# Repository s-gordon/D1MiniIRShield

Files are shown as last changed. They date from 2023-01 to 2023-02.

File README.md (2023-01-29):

# D1 Mini IR Shield

## Description

TODO

## Preview

| 3D | 2D |
| -- | -- |
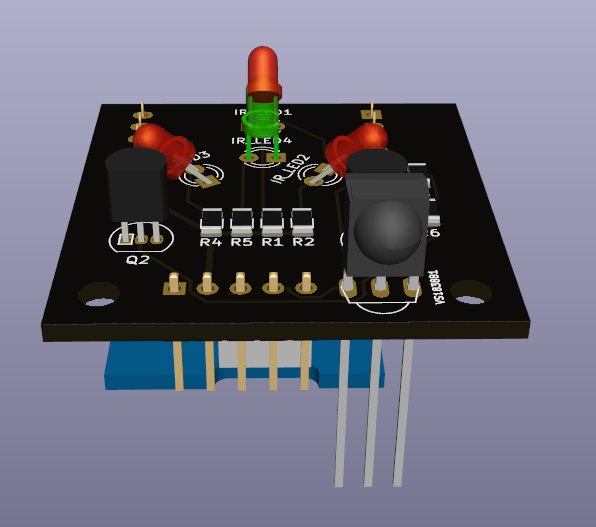
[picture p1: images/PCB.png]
3-dimensional view
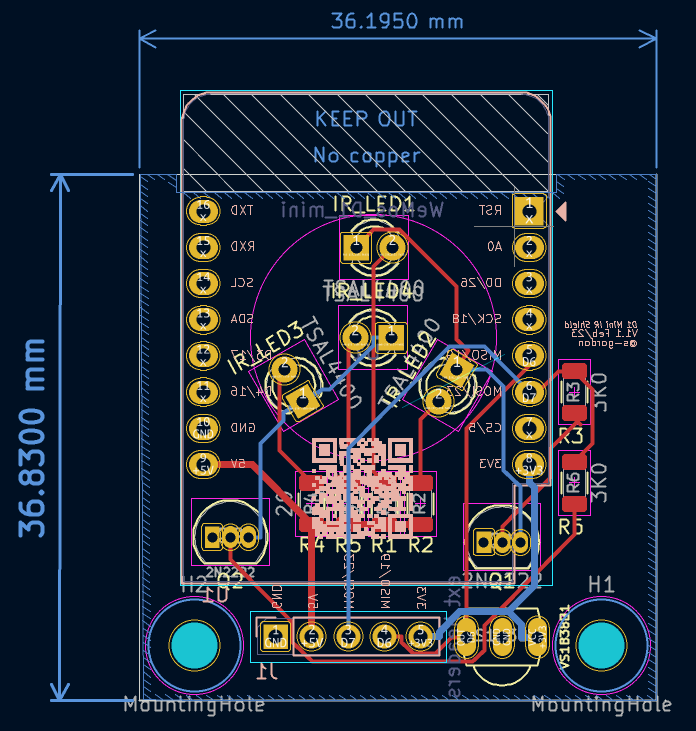
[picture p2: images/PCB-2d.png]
2-dimensional view
|  |  |

## Credit

TODO

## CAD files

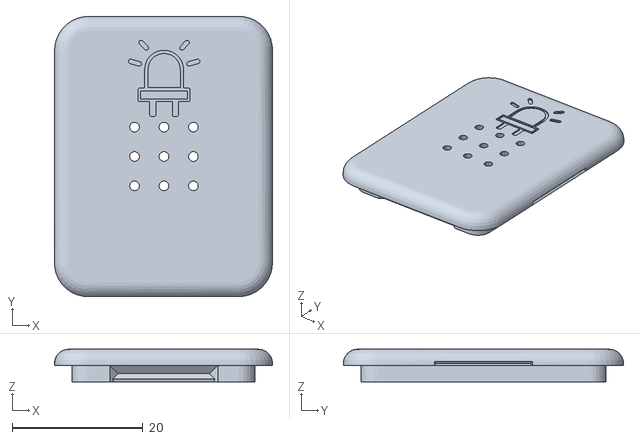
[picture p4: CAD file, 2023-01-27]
stl/case/lid.stl
33.3 x 42.9 x 5.00

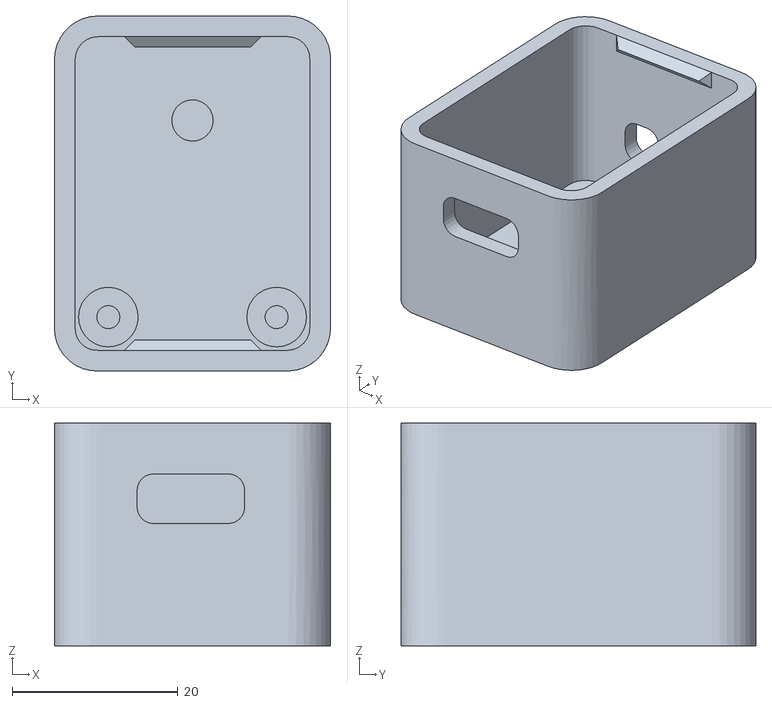
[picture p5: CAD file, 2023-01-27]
stl/case/base.stl
33.3 x 42.9 x 26.9

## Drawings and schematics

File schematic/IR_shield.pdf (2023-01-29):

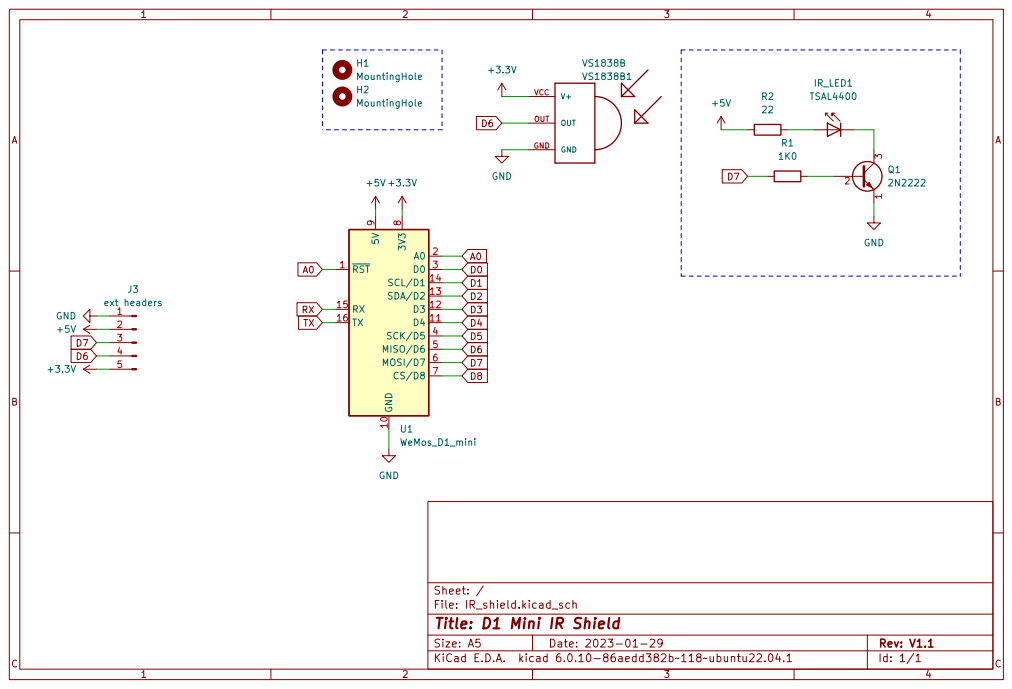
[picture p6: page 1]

Id: 1/1 Title: D1 Mini IR Shield

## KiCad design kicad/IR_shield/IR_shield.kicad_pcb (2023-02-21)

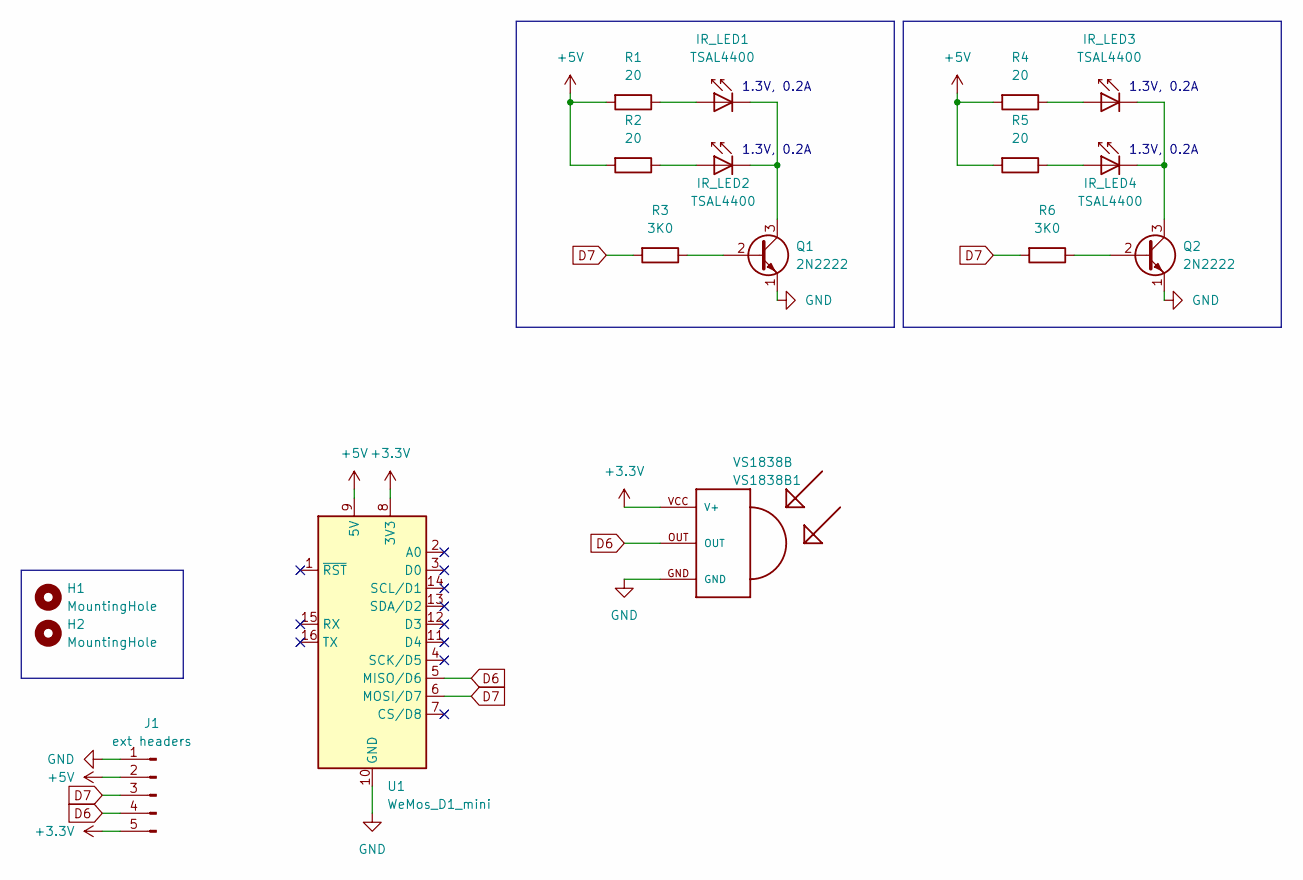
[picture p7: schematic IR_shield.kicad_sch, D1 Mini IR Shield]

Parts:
H1, H2: MountingHole; MountingHole_3.2mm_M3
IR_LED1, IR_LED2, IR_LED3, IR_LED4: TSAL4400; LED_D3.0mm
J1: ext headers; PinHeader_1x05_P2.54mm_Vertical
Q1, Q2: 2N2222; TO-92_Inline
R1, R2, R4, R5: 20; R_1206_3216Metric
R3, R6: 3K0; R_1206_3216Metric
U1: WeMos_D1_mini; WEMOS_D1_mini_light
VS1838B1: VS1838B; TSOP18XX

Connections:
+3V3: J1.5, U1.8 (3V3), VS1838B1.VCC (V+)
+5V: J1.2, R1.2, R2.2, R4.2, R5.2, U1.9 (5V)
D6: J1.4, U1.5 (MISO/D6), VS1838B1.OUT
D7: J1.3, R3.2, R6.2, U1.6 (MOSI/D7)
GND: J1.1, Q1.1 (E), Q2.1 (E), U1.10 (GND), VS1838B1.GND
unnamed: IR_LED1.1 (K), IR_LED2.1 (K), Q1.3 (C)
unnamed: IR_LED1.2 (A), R1.1
unnamed: IR_LED2.2 (A), R2.1
unnamed: IR_LED3.1 (K), IR_LED4.1 (K), Q2.3 (C)
unnamed: IR_LED3.2 (A), R4.1
unnamed: IR_LED4.2 (A), R5.1
unnamed: Q1.2 (B), R3.1
unnamed: Q2.2 (B), R6.1

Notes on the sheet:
1.3V, 0.2A

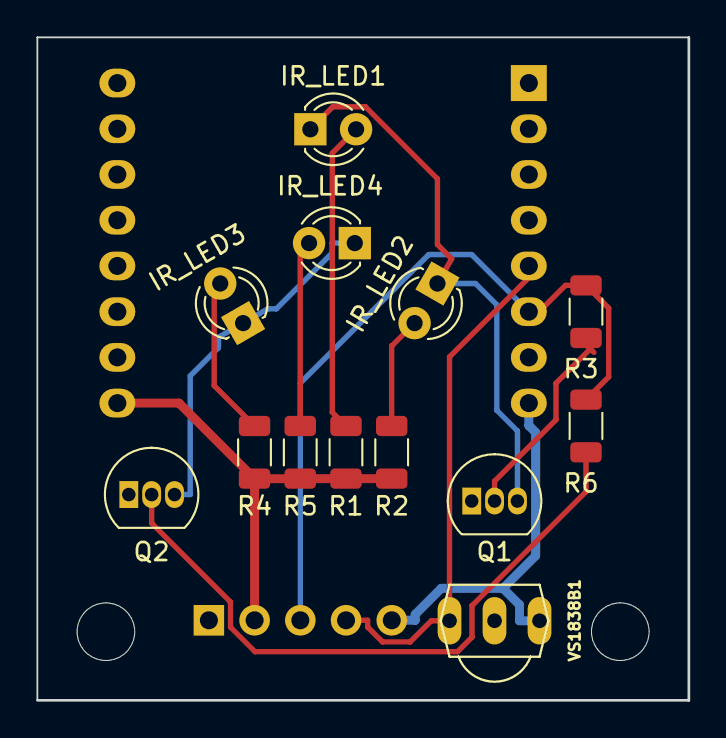
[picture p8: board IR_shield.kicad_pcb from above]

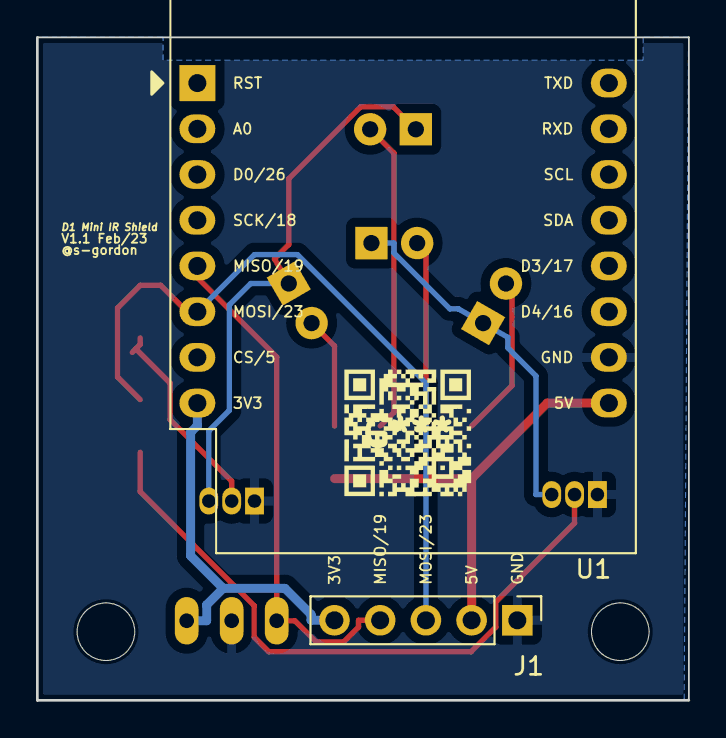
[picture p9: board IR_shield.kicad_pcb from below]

Board: 2 copper layers, 36.2 x 36.8 mm, 17 parts (2 on the bottom side), 13 nets.

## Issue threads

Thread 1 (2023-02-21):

v1.0 RC1

s-gordon, 2023-02-21:
I've ordered a set of the v1.0-RC1 board to be fabricated. These will need to be tested to make sure that everything works as expected.

s-gordon, 2023-02-21:
The board arrived earlier this week. Unfortunately some of the traces are absent on the board. These are:

- LED -ve to NPN 2N2222 collector
- IR Receiver data to D6
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

s-gordon, 2023-02-21:
I can overcome the problem by bringing the broken connections with wires as shown. After doing this (and soldering the other components) the unit functions perfectly. Both emitter and receiver work as expected through ESPHome.

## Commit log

2023-01-27 Added kicad files.
    [IR_shield.kicad_pcb, IR_shield.kicad_sch]
2023-01-27 Added QR code linking to GitHub repo to print on PCB.
2023-01-27 Added case STL.
    [base.stl, lid.stl]
2023-01-27 Reworked routing and added male header pins.
    [IR_shield.kicad_pcb, IR_shield.kicad_sch]
2023-01-27 Added logo to lid. Added nail hold for removing lid.
    [lid.stl]
2023-01-27 Corrected footprint for female headers from male headers.
    [IR_shield.kicad_pcb, IR_shield.kicad_sch]
2023-01-27 Added schematics and 3D model for PCB.
2023-01-29 Expanded margins of PCB to avoid clash with D1 Mini. 5 pin male headers changed to flat rather than sticking up.
    [IR_shield.kicad_pcb, IR_shield.kicad_sch]
2023-01-29 Fixed bad PCB image. Whoops.
2023-02-18 Reworked design to add 4 IR LEDs.
    [IR_shield.kicad_pcb, IR_shield.kicad_sch]
2023-02-21 Moved the QR code to a better location on the PCB. Likewise with text information.
    [IR_shield.kicad_pcb]
2023-02-21 Updated PCB pictures to 1.0-rc2.
